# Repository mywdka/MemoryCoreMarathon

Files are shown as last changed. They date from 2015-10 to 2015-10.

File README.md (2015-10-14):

# MemoryCoreMarathon
UNRAVEL THE CODE IV, Memory Core Marathon

# Weaving, Driving, Dreaming

Based on the Memory Core Shield from B. North and O. Nash.
Slight routing modifications done to the driver layout, silkscreen and Arduino API.

WdKA API for Unravel the code can be found in the code/ folder.

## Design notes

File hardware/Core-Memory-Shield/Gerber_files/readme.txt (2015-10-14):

These are the RS-274X gerber files for both the core board and the driver board.

The filename extensions are as follows:

GBL Bottom layer (copper)
GTL Top layer (copper)

GBS Bottom soldermask
GTS Top soldermask

GBO Bottom overlay (silkscreen)
GTO Top overlay (silkscreen)

TXT Excellon drill file	(2.4 with leading zero suppression)

GTP Top paste (used to specify stencil - necessary only for driver board)

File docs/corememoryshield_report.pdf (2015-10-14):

## Magnetic core memory reborn

Ben North, Oliver Nash

May 9, 2011

Abstract

We outline the theory of magnetic core memory, and describe the design and fabrication of a core memory Arduino shield.

## 1 Introduction

### 1.1 What is magnetic core memory?

Magnetic core memory was the most widely used form of digital com- Core memory is an old puter memory from its birth in the early 1950s until the era of in- memory technology. tegrated-circuit memory began in the early 1970s. Aside from being
extremely reliable, magnetic core memory is an appealing technology
because it is based on a very simple idea.
A magnetic core is a ring of ferrite material. It can be permanently A core, a ring of magnetic
material, stores one bit by the direction of its
magnetisation.

magnetised either clockwise or anti-clockwise about its axis just as a vertical bar magnet can be magnetised up or down. We can then
turn a magnetic core into a bit of digital memory by letting these two
magnetisation states correspond to 0 and 1.
The core needs no power to retain its data. In other words, core It provides non-volatile memory is a form of non-volatile storage like modern hard disk drives, storage.
although in its day it fulfilled the ‘high-speed’ role of modern RAM.
With many such cores, large memory modules were made, such as
this example from a CDC machine of the mid-1960s. The right-hand
image shows a close-up of the cores themselves.

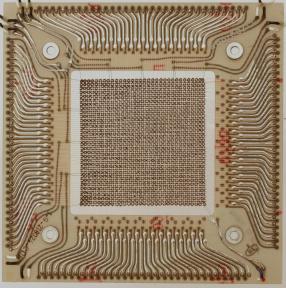
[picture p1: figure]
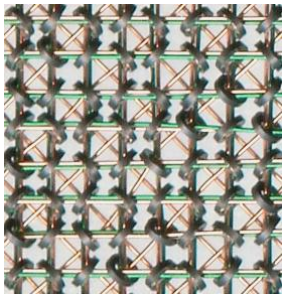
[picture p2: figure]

50 mm | 2 mm

1

Cores were c.1 mm across, | As the technology developed [1], the cores shrank from c.2 mm di-
and ran at c.1 MHz. Core stores had up to 500,000 cores. | ameter in the early 1950s to c.0·4 mm by the early 1970s. Access speeds
| rose at the same time, from about 200 kHz to over 1 MHz, and core
| memory modules were manufactured with as many as over half a mil-
| lion cores. Furthermore, as recently as 2004, a magnetic core memory
| system was found still in service in a telephony control system.
It is still an interesting | Magnetic core memory continues to capture the imaginations of
technology even today. | modern enthusiasts [2, 3], and it is also the origin of the term core
| dump, to mean an on-disk image of the main memory of a process.

### 1.2 What is an Arduino?

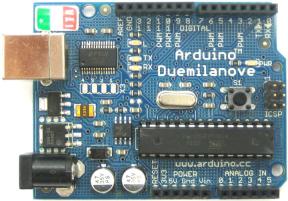
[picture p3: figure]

The Arduino is a popular, | The Arduino, whose Duemilanove version is shown above [5], is an
easy-to-use, open design microprocessor board with IO capabilities. | open-source physical computing device. It has removed many of the
| hurdles for people wishing to explore embedded microprocessing. An
| Arduino is a small single-board computer based on an Atmel AVR
| microprocessor, with supporting components to handle USB commu-
| nications and provide easy access to input/output pins. The developer
| programs the on-board microprocessor using an IDE running on a PC.
| It has proved very popular, with six-figure sales, and has been used
| in projects as diverse as autopilots for radio-controlled aeroplanes, and
| CNC sewing machines.
Add-on shields exist, | Several expansion modules exist, allowing the Arduino to perform
providing specialist interfacing or control functions. | a greater variety of tasks. These secondary modules, or shields, are
| circuit boards that plug into the Arduino’s pin headers, and supply
| additional hardware to, for example, drive motors or servos, interface
| with wireless communication modules, or communicate over Ethernet.

### 1.3 A core-store shield

We set ourselves the | We had developed an interest in the principles and practice of core
challenge of creating a core memory Arduino shield. | memory, and the creation of a modern core memory module struck us
| as an appealing challenge. Eventually a pleasing idea suggested itself:
| we decided to build a magnetic core memory Arduino shield.
New-old-stock cores; | Our project was made possible thanks to the existence of a sup-
modern components. | ply of surplus ferrite cores manufactured in the 1980s for the magnetic
| core memory systems of the time. We decided that we would use these
| old cores but permit ourselves to use modern components (transistors,
| integrated-circuit logic gates, etc.). This made our work enormously
| 2

easier than that of the original core memory inventors and manufacturers. Also, we knew that our end goal was possible.
We succeeded in building an extremely reliable 32-bit core memory It worked. shield for the Arduino. It can be used as storage for the Arduino, or alternatively, any modern computing device with a USB port can now
read and write to magnetic core memory.

## 2 Principles of core memory

### 2.1 Magnetic hysteresis

A ferrimagnetic substance has two distinct permanently magnetised states. In our case, these are clockwise and anti-clockwise round the cores. The key to their use as computer memory is their behaviour when an external magnetic field is applied — they exhibit hysteresis.

A weak external field has no effect
If we apply a weak external magnetic field around a core, and then remove it, there is no lasting effect on the core’s magnetisation:

Start off with a core magnetised in the anti-clockwise direction:

Apply a weak clockwise external field. This reduces the strength of the anti-clockwise magnetism in the core:

But when the external field is removed, the magnetism in the core ‘springs back’ to its original state:

A weak anti-clockwise field similarly produces no lasting change.

Strong external fields cause the magnetisation to switch However, if we apply a sufficiently strong magnetic field in the opposite direction, the core will switch from one magnetic state to the other:

Start off with a core magnetised in the anti-clockwise direction:

Apply a strong clockwise external field. This switches the core’s magnetism, and the core now has clockwise magnetism:

When this external field is removed, the magnetism in
the core reduces slightly in strength, but remains clockwise:

A strong field in the same direction as the core’s existing magnetisation has no lasting effect — the core is saturated and can be magnetised no further in that direction.

3

### 2.2 The magnetic field of a current-carrying wire

Current in a wire creates a | The next essential physical fact is that a DC current in a wire creates
magnetic field. | a magnetic field circulating about the wire, whose strength is propor-
tional to the size of the current. If we reverse the direction of the current, the magnetic field circulates in the opposite direction:

Small current down;
weak clockwise field

Large current down;
strong clockwise field

Small current up; weak
anti-c/w field
Large | current | up;
strong anti-c/w field

### 2.3 Writing to a one-bit core memory system

We can write a bit by We now know enough to write one bit of core memory. Having threaded
driving appropriate
currents.

a wire through a core, we can cause the core to become magnetised in the clockwise direction by passing a strong enough current in one direction through the wire, and we can cause the core to become magnetised in the anti-clockwise direction by passing a strong enough current in the opposite direction. These two operations correspond to writing 0 and 1 to the core. The magnetisation of the core, and so the bit stored, remains even after the current stops flowing.

The core is magnetised anti-clockwise, and therefore holds the bit 1. No current flows through the wire.

A large current is supplied, generating a strong magnetic field. This switches the core’s magnetisation to clockwise.

When the current is turned off, the core remains magnetised clockwise, therefore now holding 0.

### 2.4 Reading from a one-bit core memory system

But: how do we read the | Core memory would probably have been a lot less popular had it been
state of the core? | a write-only technology. To see how to read from the core, we need a
| further piece of physics: a changing magnetic field induces a voltage.
When a core switches, it | Consider a core which is magnetised anti-clockwise. If we apply
induces a voltage. | current which tries to increase this anti-clockwise magnetisation, it
| does not in fact change the magnetic field in the core much — it is
| already saturated. If, however, we apply enough current in the opposite
| direction, the core switches to be magnetised clockwise, as shown above.
| This process takes a small amount of time, around 1 µs for typical cores.
| 4

During that time, the magnetic field is undergoing a large change, and
so induces a noticeable voltage.
The setup for reading the state of a core then is to have two wires A second wire senses the
passing through the core. We use one wire, the drive line | induced voltage. , for driving
current back and forth and so to set the state of the core, and we have
circuitry connected to the second wire, the sense line, to measure the
induced voltages.
We start the process of reading the core by writing a 0 to it using To read: write a 0; check if
the core switched. If it
did, it was a 1.

the drive line. If we observe no significant induced voltage on the sense
line then we learn the core was already in state 0. If, however, we observe a large induced voltage on the sense line then we learn that
the core contained a 1 (and we then write 1 back to the core). The
memory is said to operate with a destructive read.
At this point it may help to make this more concrete by exhibiting We measured the sense signals from our cores. some real data. Below we present the results of one of our experiments in which we measured the induced voltage on the sense line when writing 0 to a core which contained 1, and when writing 0 to a core which
already contained 0.

If a core switches from one magnetisation
direction to the other, the changing magnetic field induces a voltage that peaks at c.35 mV, staying above 20 mV for c.600 ns:

However, if the applied field is in the same direction as the core’s existing magnetisation, no switching takes places, and we observe a negligible voltage:

20 mV

40 mV

2 µs pulse | 2 µs pulse

We also see voltage ‘spikes’ caused by the drive line currents switching on and off. These transformer-action spikes are significant in magnitude but are short and temporally separated from the switching signal. The pulse shown is in fact the base drive of transistors, and the turn-on and turn-off delays are visible.
We could now build a one-bit read-write core memory system.

### 2.5 Arrays of cores and half-select currents

However, we want to have more than one bit of memory without need- Imposing only half the field leaves the core alone. ing one drive line per core. We make use of a feature of the hysteresis behaviour of the core. We previously talked in terms of ‘weak’ or
‘strong’ external magnetic fields. Slightly more quantitatively: the core
is not switched by a field which is half as strong as one which is just
strong enough to switch the core. The field is proportional to the current in the drive line, so if we pass half the current required to just
switch a core through the drive line, the core will not switch state.
Now suppose we have nm cores and we arrange them in an n × m A 2-D array gives efficient control of every core. rectangular array such that each core has one of n horizontal and one
of m vertical drive lines passing through it. With this setup we can

5

selectively set the (i, j)th core and no other by simultaneously driving the ith vertical drive line and jth horizontal drive line in the appropriate directions, each with half the current required for switching. For example, in a 4×4 array, with the cores viewed edge-on, we switch the core shown:

One core receives a full field and switches.

Nine cores like this are completely unaffected.

Six cores like this receive a half-field and are unaffected.

We only need O(

√
N) drive lines for an array of N cores. In total, each core will have three wires threaded through it: two perpendicular drive lines, and a sense line. A single sense line can be threaded through all cores in an array, a point we return to below.

### 2.6 Exploiting anti-coincidence

One more trick doubles The picture we should now have in mind of a core memory module is
the number of cores we
can address.

a rectangular array of cores, with one vertical and one horizontal drive line passing through each core. There is a further drive-line economy, which cuts in half the number of drive lines in one dimension.
Two states out of four do | Consider a core with its two drive lines. There are then four combi-
nothing. | nations of current direction. Two combinations produce a reinforcing
field round the core, but in the other two, the fields cancel round the core:
Reinforce to write 0: | Reinforce to write 1: | Cancel; no effect: | Cancel; no effect:

We say the currents or fields are coincident if they reinforce, and anti-coincident if they cancel.
We can use those two | Now consider two cores arranged as below. We still have two drive
states. | lines, but we have turned one of the drive lines through two right angles
so that it passes through both cores but in opposite directions. If we now consider the four possible simultaneous states of the drive lines, we find that all possible combinations are put to use:
Write 0 to left core: | Write 1 to left core: | Write 0 to right core: | Write 1 to right core:

6

To take the concrete example of the small core array we built, we One sense loop snakes through all cores. show a 8 × 4 array. We also now illustrate the single sense line which runs through all cores. The alternating alignment of the cores makes
the threading of the sense loop easier, and also reduces the transformer-action spikes.

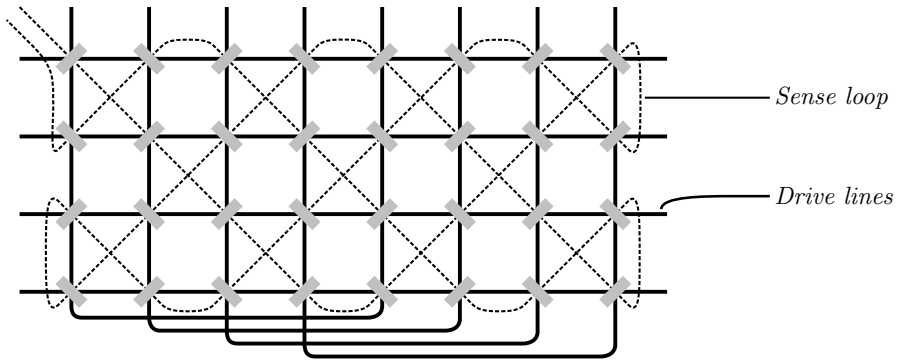
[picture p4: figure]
Sense loop; Drive lines

The array of cores can be thought of as two halves, with each core in the left half having an anti-coincident partner in the right half sharing the same pair of drive lines.

## 3 Our implementation

To implement these principles, we have to solve a few fairly distinct problems. We must be able to drive current through the drive lines; decide which drive lines need to have current driven through them; and sense when an induced ‘switching signal’ occurs.

### 3.1 A current-driving circuit

As noted above, we organise the 32-bit module as a rectangular array The drive circuit is two
copies (X and Y ) of one
problem: driving one of
four lines in either
direction.

with 4 rows and 8 columns in which the columns are paired as above using anti-coincidence. As a result, we have 4 vertical and 4 horizontal drive lines to control. Our current-driving problem is thus two instances
of the same problem: we need to be able to select one of four lines, and
to specify a direction in which to drive current along that line.
Our current sources and sinks are transistors, and we could ac- Drive the four lines as ‘two by two’. complish our goal by connecting each end of each drive line to the
collectors of both a PNP and an NPN transistor (i.e., by using four
H-bridge circuits). This would work, but would be inefficient in terms
of the number of transistors used. By introducing a few diodes, we can
use a design with half as many transistors.
By turning on the correct transistors in the following circuit, we can send current in either direction through any of the drive lines. The resistors R1 and R2 control how much current flows. We discuss their value below.

7

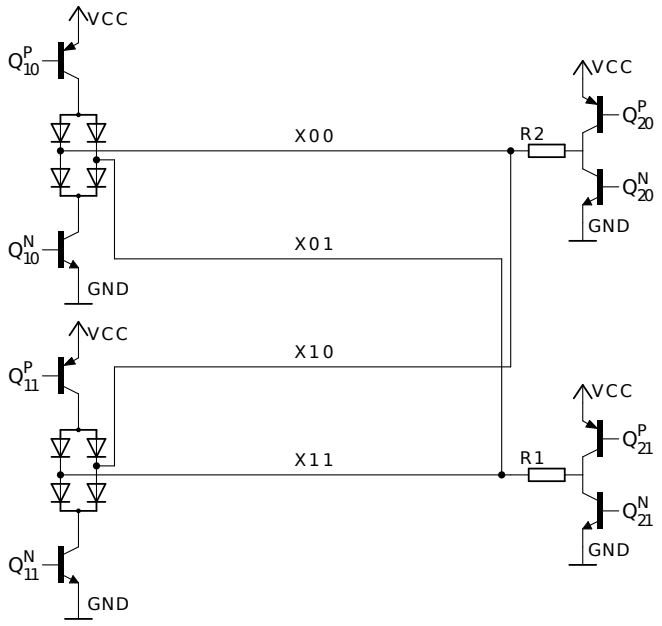
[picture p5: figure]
GND; VCC

Calibrating the half-select current

Experiments determine As we have already discussed, it is important that we drive the right
how much current we
should use.

amount of current. It must be low enough that the magnetic field produced by the current in one drive line is not enough to switch a core, but high enough that the combined field from two coincident currents does produce switching. We determined the range of possible values of current for our cores empirically and established that any value in the range 250–340 mA works. We set the current by choosing appropriate values for the resistors in the drive circuit above.

### 3.2 Addressing

Which transistors should | In the circuit above, we want to know which transistors to turn on
we turn on? | to drive current left or right in one of the four lines. We must be
able to pulse this current, and so we need to be able to stop all drive currents. Let the enable Boolean variable be E. Let the variable DX give the direction, with DX = 0 being leftwards. In order to drive the line XA1A2

in the direction DX (as long as E is asserted), the base of transistor QP
11, for example, must be taken high or low according to QP
11 = E ∧ DX ∧ A1· In words, QP
11 must be on (i.e., its base must be pulled low) exactly when we are enabled (E = 1) and we wish to drive current rightwards (DX = 1) through either X10 or X11 (those two lines have A1 = 1). The formulae for all eight transistors are:

QP
10 = E ∧ DX ∧ A1 QP
20 = E ∧ DX ∧ A2
QN

10 = E ∧ DX ∧ A1 QN
20 = E ∧ DX ∧ A2
QP

11 = E ∧ DX ∧ A1 QP
21 = E ∧ DX ∧ A2
QN

11 = E ∧ DX ∧ A1 QN
21 = E ∧ DX ∧ A2

8

Combining the X and Y drive addressing

Recall that the current-driving circuitry consists of two instances of this Translating from ‘currents
in lines’ to ‘address and
data’.

driving circuit, horizontal and vertical. We thus have bits A1, A2, and
DX for the first instance and A3, A4, and DY , say, for the second. We can generate a switching field in either direction for any of our 32 cores by choosing values for these six bits, and then controlling transistor bases accordingly. Furthermore, looking back at section 2.6, we see that the tuple (A1, A2, A3, A4) determines a pair of anti-coincident partner cores and that it is the value of A0 := DX ⊕ DY that distinguishes between these two partner cores. Therefore we reparameterise our six control bits in terms of the five-bit address A4A3A2A1A0 and the single data bit D := DX. We then have DY = DX ⊕A0. The 32 cores are now numbered, since each core has a unique five-bit address A4A3A2A1A0. The layout of these addresses in the 8 × 4 array may appear a little haphazard, but this does not matter.

### 3.3 Sensing

With the current-driving and addressing circuitry in place, it remains How to detect the bulging only to describe how to detect the presence or absence of a core- switching signal? switching signal on the sense line. We chose the comparator-based
circuit described in [1] (and apparently of unknown German origin):

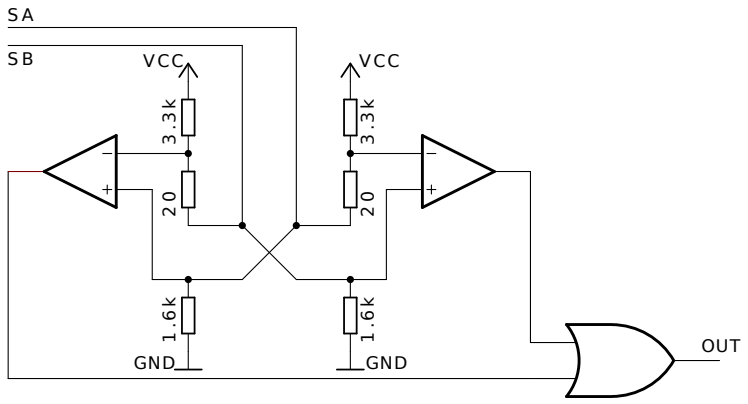
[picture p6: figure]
OUT; GND

VCC | VCC 3 .3 k 2 0 1 .6 k | 3 .3 k 2 0 1 .6 k

The sense line, described above, is threaded once through each of the
32 cores, and its ends are connected to the lines marked SA and SB.
The obvious two-fold symmetry of this circuit reflects the possibility Need to detect positive and negative sense bulges. that a sense pulse from a switching core can bias SA positively or negatively relative to SB depending on whether a core is switching
from a clockwise to an anti-clockwise magnetisation state relative to
the sense line or vice-versa.
The resistors ensure that, when no voltage is present across SA/SB, With an input of at least
±20 mV, one comparator’s
output goes high.

each comparator’s inverting input is 20 mV above its non-inverting, and
so both outputs are low. If a positive sense pulse occurs, causing SA to rise more than 20 mV above SB, the left comparator will detect this and output ‘high’. Conversely for a negative sense pulse, the right

9

comparator will fire. We or the two to detect pulses of either polarity. The threshold of 20 mV was chosen by experiment.
Capture sense output at The final detail of the sense circuitry is that we used a timed latch to
the right moment.

t=0 t=650ns:
latch sense output

t=2us

sense
threshold

catch and store the output of the or gate at the appropriate moment. This ensures that we are not affected by any high comparator outputs caused by the transformer-action spikes. The timer delay was chosen by experiment as 650 ns, although any value 500–900 ns worked.

## 4 Finished product

### 4.1 Complete circuit

Combining these pieces, we arrive at the final circuit, which we give in appendix A. The design splits the shield into a driver board and a plug-in core board, as shown in this photograph of the two boards plugged into the Arduino:

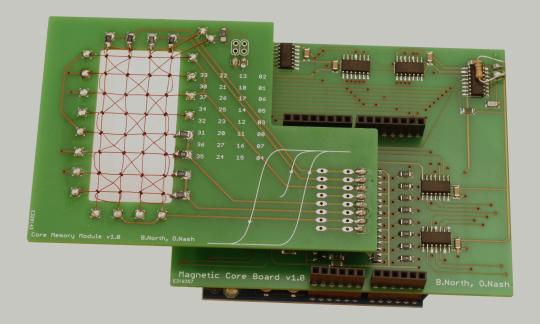
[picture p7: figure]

### 4.2 Fabrication

Our design files are | We finally achieved our goal of building a core memory shield by having
available. | our schematics fabricated as PCBs. Owing to some late design changes,
| we then had to patch the boards slightly; the circuits described here in-
| clude the changes. Eagle files for these schematics and PCBs as well as
| the Gerber files are available in the online version of this document [6].
| Also contained in the Eagle files are the part numbers for the various
| components (transistors, logic gates, comparators, etc.) that we used.

### 4.3 API and testing

How to write to and read | Once the core board, driver board and Arduino have been appropriately
from the cores from Arduino code. | mated, it is easy to use the Arduino to read from and write to the core
| memory array. To send a write pulse to a core, the Arduino writes the
| data bit to digital pin 8, writes the address of the core in question to
| 10

digital pins 3–7 and then asserts enable (digital pin 2) for 2 µs. Once this is done, reading digital pin 9 reveals whether the core changed state. Cycle time is such that a 32-bit operation takes 0·5 ms, although
preliminary experiments suggest that by being more aggressive on the
timings we could bring this down to 0·3 ms.
These operations are presented as the functions write_bit and A simple API and
serial-based CLI is
available.

read_bit. Loops turn these into write_word and read_word, to act
on the whole core board as a single 32-bit unsigned integer. A further natural operation is a bit exchange. This, in one operation, writes a new data bit to a core, and returns the old value, which can be deduced as (latched-sense-output) xor (new-data). The source-code for this API,
with a command-line interface presented on the serial port, is available
for download [6].
We used this interface to extensively test the core memory shield. The core memory shield
performed error-free for

### 10 bln operations, running

for 100 hrs.

After running continuously for over one hundred hours, the shield had performed over ten billion successful bit-exchange operations without a single error.

## 5 Final words

We hope that our work here might encourage others to take an interest in both the theory and the practice of core memory. For further reading, excellent descriptions are given by Hilpert [1] and by Jones [4]. Building a reliable 32-bit core memory shield for the Arduino proved to be a natural stopping point for our work, but there is certainly more that could be done. Some ideas for future work that appealed to us:

- Many core memory arrays from the heyday of core memory still exist and indeed are easy to find for sale (e.g., on eBay). It might be a fun challenge to build a driver module to write to and read from these old arrays. Perhaps with care and luck one could even recover some 50-year-old data?
- A completely different approach to core memory, with a nondestructive read cycle, was invented by Eiichi Goto in the mid-1950s, and was incorporated in the Japanese Parametron Computer 1 (see [7] for a description). It would be very interesting to re-implement this significantly different core memory technology.
- In practice, a group of core memory modules of the type described here, known as planes, were combined into a core store. All planes could be accessed simultaneously by introducing an inhibit line [4]. Constructing an 8-bit wide store would be a worthwhile challenge.

11

## A Circuits

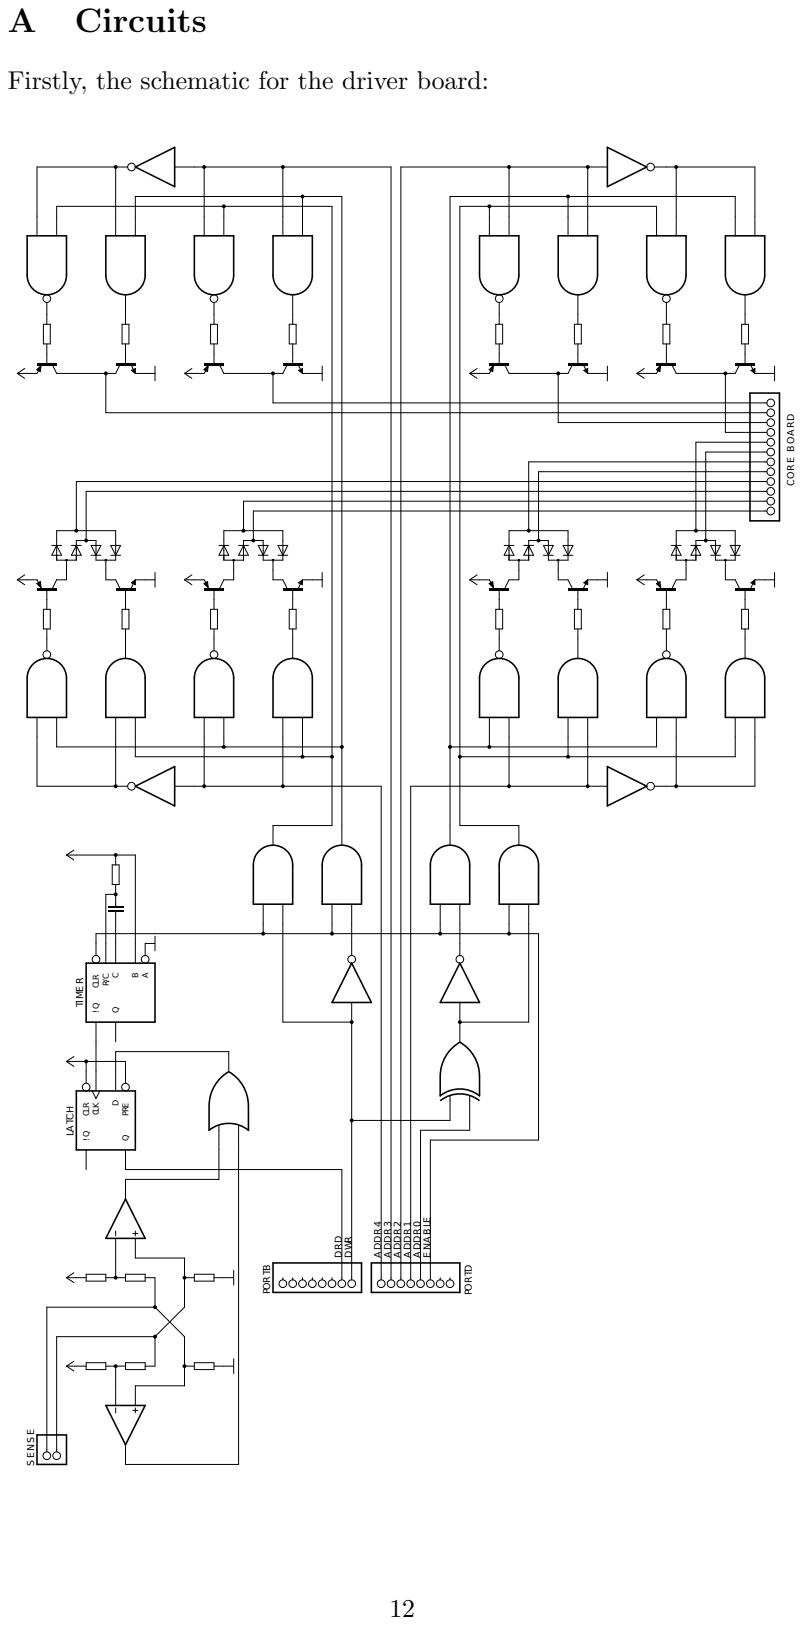
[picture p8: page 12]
DRD DWR; ADDR4; ADDR3; ADDR2; ADDR1; ADDR0; E NABLE; !Q CLR; CLK; PRE Q; LATCH; CLR; TIME R; PORTB; PORTD; CORE BOARD

Firstly, the schematic for the driver board:

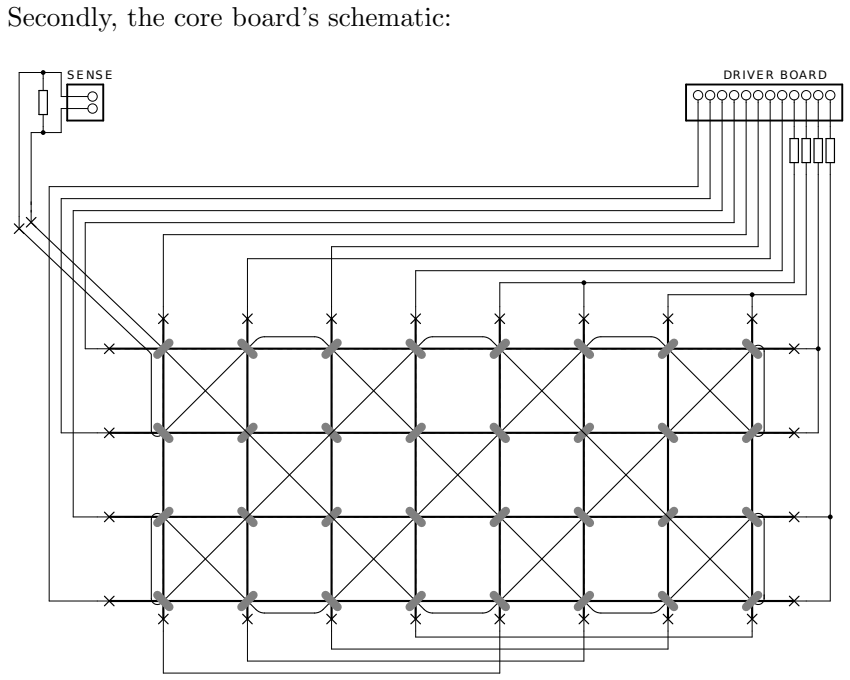
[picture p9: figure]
Secondly, the core board’s schematic:; DRIVE R BOARD

The terminating resistor across the sense loop provides a path for the current caused by the induced voltage round the loop.

## References

[1] B. Hilpert. Magnetic core memory systems. http://www.cs.ubc.ca/~hilpert/e/coremem/index.html.
[2] W. Holder. One bit ferrite core memory. http://sites.google.com/site/wayneholder/one-bit-ferrite-core-memory.
[3] A. Holme. Magnetic core memory. http://www.holmea.demon.co.uk/Core/Flipper.htm.
[4] J.R. Jones. Coincident current ferrite core memories. Byte, 11:6–16, July 1976.
[5] D. Mellis. Photograph of Arduino Duemilanove, cc-by-2·0. http: //www.flickr.com/photos/mellis/4784965878/.
[6] B. North and O. Nash. Magnetic core memory reborn. http: //www.corememoryshield.com/.
[7] E. Wada. The Parametron Computer PC-1 and its initial input routine. In P. Rojas and U. Hashagen, editors, The first computers: History and architecture, pages 435–452. MIT Press, 2000.

13

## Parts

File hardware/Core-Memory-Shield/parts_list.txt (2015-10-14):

Below is the list of necessary parts for building a magnetic core memory
Arduino shield v1.1.  We found all of these parts (including the cores
themselves) easily available on at least one of http://www.ebay.com and
http://www.farnell.com and had our PCBs manufactured by
http://www.eurocircuits.com.

One important note is that the value of the four drive resistors, listed
as 18ohm, may need to be adjusted if the cores used are sufficiently
different to ours.

DRIVING:
8x 2N4401/MMBT4401 transistor (SOT-23 package)
8x 2N4403/MMBT4403 transistor (SOT-23 package)
17x 220ohm 1% resistor (1206 package)
4x 18ohm 1% resistor (1206 package) [May need calibration as described above.]
4x BAW56 diode pair (SOT-23 package)
4x BAV70 diode pair (SOT-23 package)

SENSING:
2x 1.3k 1% resistor (1206 package)
2x 3.3k 1% resistor (1206 package)
2x 20ohm 1% resistor (1206 package)
1x dual MAX907CPAS comparator (SO08 package)
2x 4.7k resistor (1206 package)

LATCHING, TIMING:
1x dual 74HC74D latch (SO14 package)
1x dual 74HC123D timer (SO16 package)
1x 47pF capacitor (1206 package)
1x 12.5k resistor (1206 package)

ADDRESSING:
1x hex 74HC04D (SO14 package)
1x quad 74HC86D (SO14 package)
3x quad 74HC08D (SO14 package)
2x quad 74HC00D (SO14 package)

BYPASS/FILTER CAPS:
10x 0.1uF tantalum capacitor (1206 package)
1x 47uF tantalum capacitor (1206 package)

CONNECTIONS:
2x 0.1" (1x8)-pin header (Arduino stackable)
2x 0.1" (1x6)-pin header (Arduino stackable)
1x 0.1" (1x12)-pin header (male)
1x 0.1" (1x2)-pin header (male)
1x 0.1" (1x12)-pin header (female)
1x 0.1" (1x2)-pin header (female)

PCBs:
1x North-Nash driver board v1.1
1x Laser-cut stencil for driver board v1.1
1x North-Nash core board v1.1
~10g solder paste

CORES:
32x ~1mm hard ferrite cores (with wide hysteresis loop)
Several metres of 0.20mm diameter glazed copper wire.

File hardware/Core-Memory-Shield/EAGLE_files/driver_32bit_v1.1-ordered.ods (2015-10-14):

Qty | Value | Parts | Description
Resistors
2 | 3.3k | R1, R4 | RESISTOR, European symbol
2 | 20 | R2, R5 | RESISTOR, European symbol
2 | 1.6k | R3, R6 | RESISTOR, European symbol
16 | 220 | R8, R9, R11, R12, R14, R15, R17, R18, R20, R21, R23, R24, R26, R27, R29, R30 | RESISTOR, European symbol
1 | 12.5k | R31 | RESISTOR, European symbol
2 | 4.7k | R32, R33 | RESISTOR, European symbol
1 | 1.5k | R34 | RESISTOR, European symbol
Capacitors
1 | 50pF | C0 | CAPACITOR, European symbol
10 | 0.1uF | C1, C2, C3, C4, C5, C6, C7, C8, C9, C10 | CAPACITOR, European symbol
1 | 47uF | C11 | CAPACITOR, European symbol
Transistors
8 | 2N4401 | T1, T3, T5, T7, T9, T11, T13, T15 | NPN Transistror
8 | 2N4403 | T2, T4, T6, T8, T10, T12, T14, T16 | PNP Transistror
Diodes
4 | BAW56 | D1, D2, D5, D6 | Dual DIODE Cathode-Anode|Anode-Cathode
4 | BAV70 | D3, D4, D7, D8 | Dual DIODE Anode-Cathode|Cathode-Anode
IC
1 | 74HC74D | IC1 | Dual D type positive edge triggered FLIP FLOP, preset and clear
1 | 74HC123D | IC2 | Retriggerable monostable MULTIVIBRATOR
1 | MAX907CPASO08 | IC3 | COMPARATOR
3 | 74HC08D | IC4, IC7, IC10 | Quad 2-input AND gate
1 | 74HC04D | IC5 | Hex INVERTER
1 | 74HC86D | IC6 | Quad 2-input EXCLUSIV-OR (XOR) gate
2 | 74HC00D | IC8, IC9 | Quad 2-input NAND gate
Headers
1 | PORTB | JP2 | PIN HEADER
1 | PORTD | JP1 | PIN HEADER
1 | ANALOG | JP5 | PIN HEADER
1 | PWR | JP4 | PIN HEADER
1 | SENSE | JP3 | PIN HEADER
1 | CORE BOARD | JP6 | PIN HEADER

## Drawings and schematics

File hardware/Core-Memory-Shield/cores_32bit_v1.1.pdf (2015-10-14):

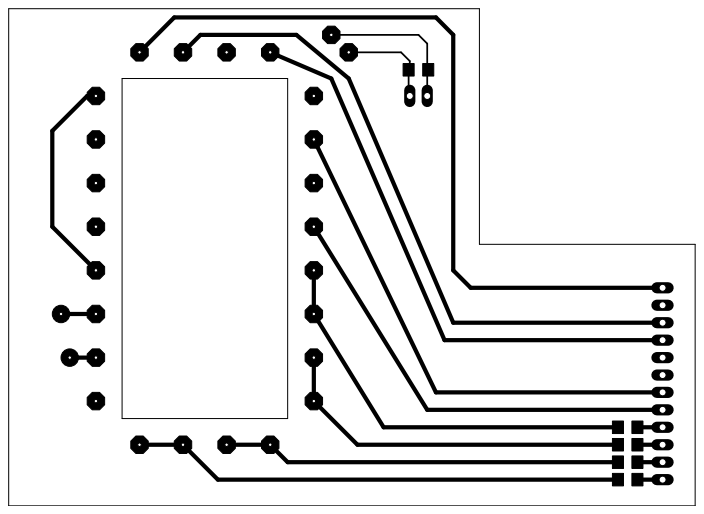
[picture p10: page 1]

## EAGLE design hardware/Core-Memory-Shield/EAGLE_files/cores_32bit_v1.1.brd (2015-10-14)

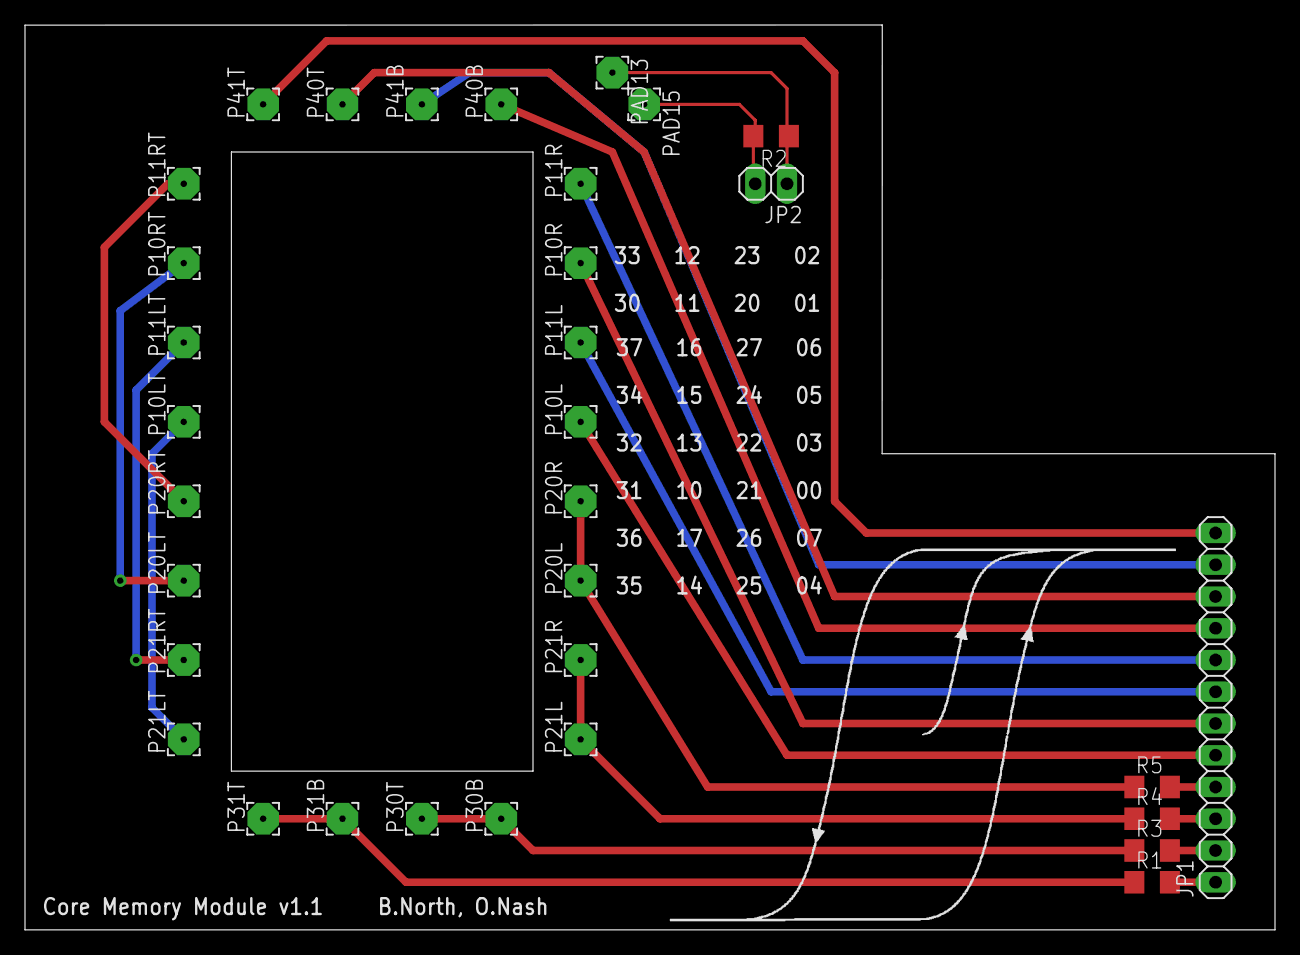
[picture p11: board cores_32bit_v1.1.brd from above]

Board: 2 copper layers, 100.0 x 72.4 mm, 33 parts (0 on the bottom side), 22 nets.

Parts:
JP1: DRIVER BOARD; 1X12
JP2: SENSE; 1X02
P10L, P10LT, P10R, P10RT, P11L, P11LT, P11R, P11RT, P20L, P20LT, P20R, P20RT, P21L, P21LT, P21R, P21RT, P30B, P30T, P31B, P31T, P40B, P40T, P41B, P41T: WIREPAD2,54/1,1; 2,54/1,1
PAD13, PAD15: WIREPAD2,54/1,1; 2,54/1,1
R1, R3, R4, R5: 18; R1206
R2: 220; R1206

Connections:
D10A: JP1.5, P10L.1
D10B: JP1.6, P10R.1
D11A: JP1.7, P11L.1
D11B: JP1.8, P11R.1
D20: P20L.1, P20R.1, R5.1
D21: P21L.1, P21R.1, R4.1
D30: P30B.1, P30T.1, R3.1
D31: P31B.1, P31T.1, R1.1
D40A: JP1.9, P40B.1
D40B: JP1.10, P40T.1
D41A: JP1.11, P41B.1
D41B: JP1.12, P41T.1
unnamed: JP2.1, PAD13.1, R2.1
unnamed: JP2.2, PAD15.1, R2.2
unnamed: JP1.1, R1.2
unnamed: JP1.2, R3.2
unnamed: JP1.3, R4.2
unnamed: JP1.4, R5.2
unnamed: P10LT.1, P21LT.1
unnamed: P11LT.1, P21RT.1
unnamed: P10RT.1, P20LT.1
unnamed: P11RT.1, P20RT.1

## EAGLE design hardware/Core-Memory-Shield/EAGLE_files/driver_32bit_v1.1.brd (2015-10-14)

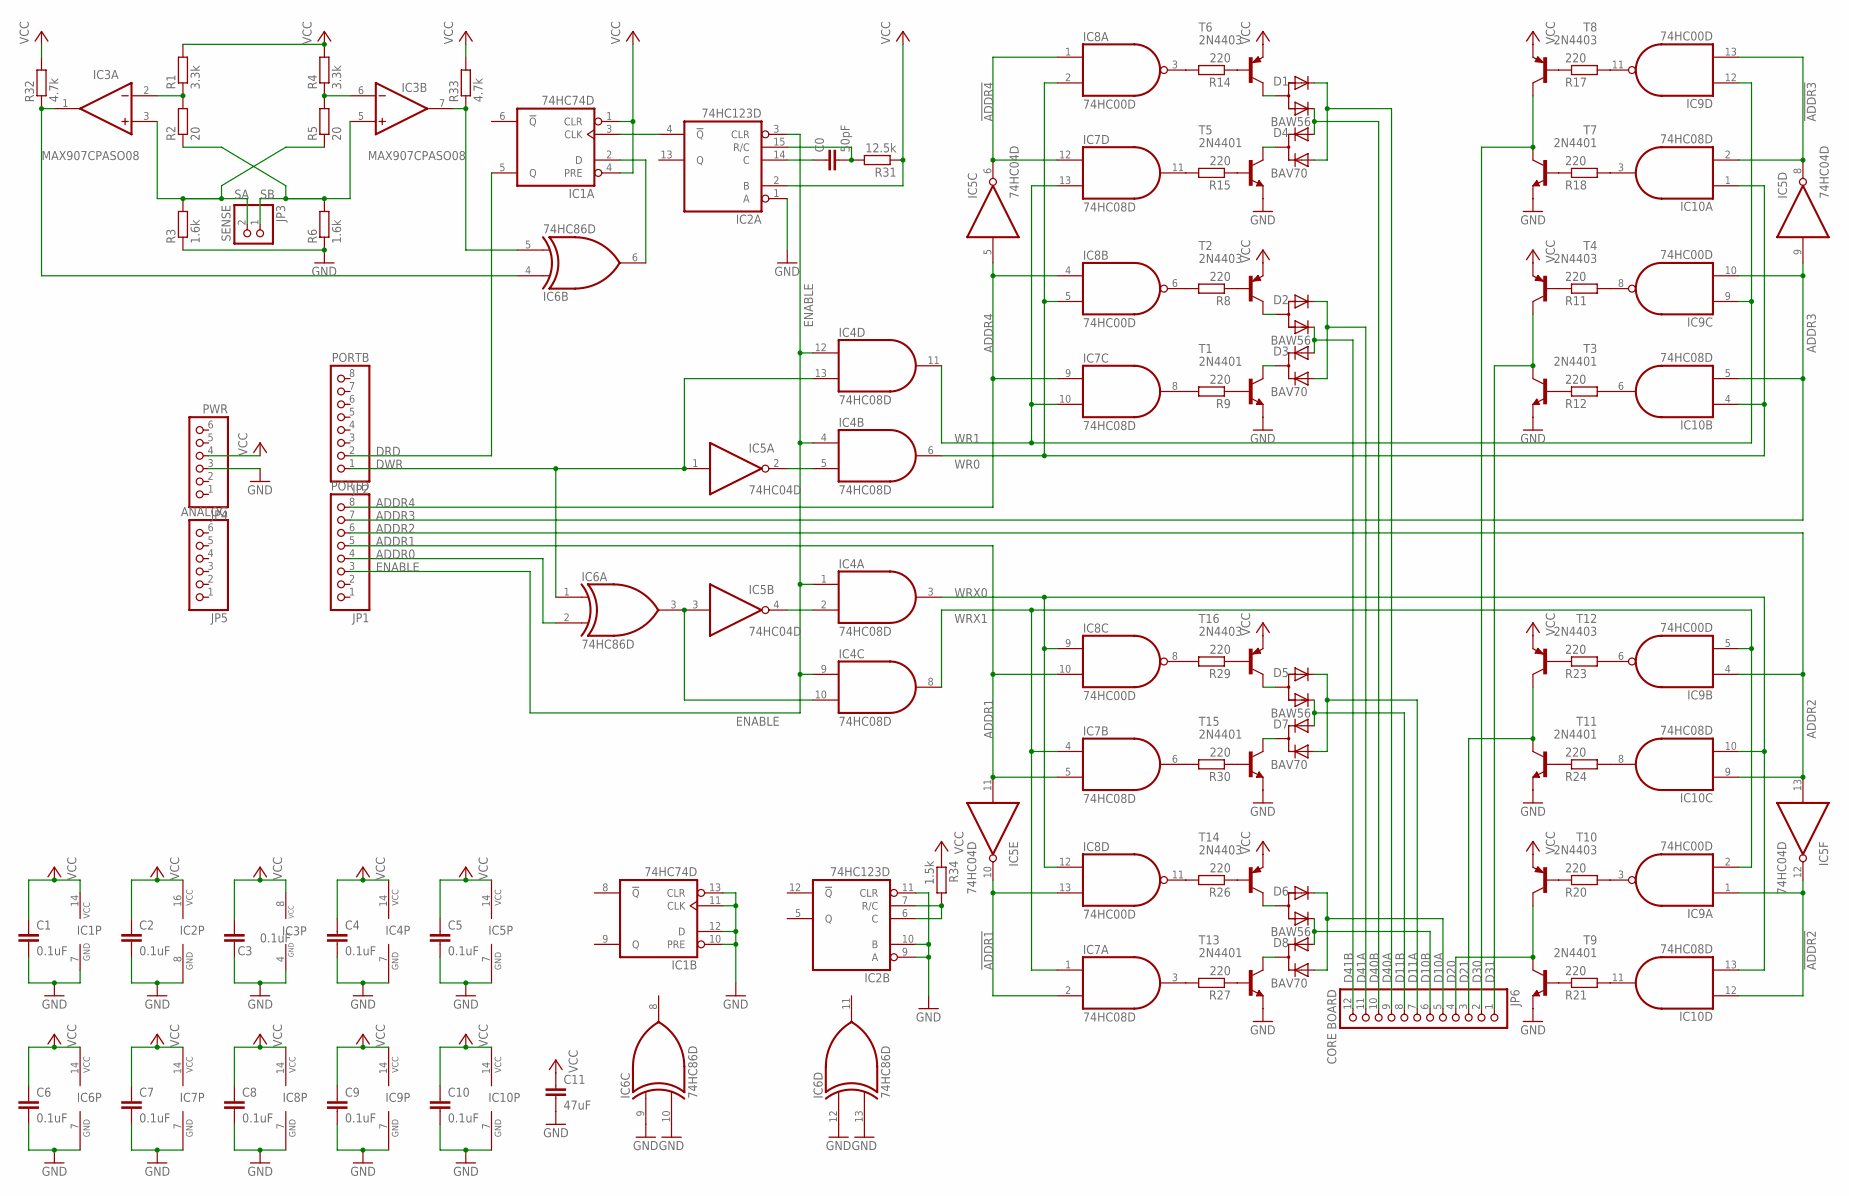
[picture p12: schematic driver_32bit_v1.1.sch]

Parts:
C0: 50pF; C1206
C1, C2, C3, C4, C5, C6, C7, C8, C9, C10: 0.1uF; C1206
C11: 47uF; C1206
D1, D2, D5, D6: BAW56; SOT23; MPN BAW56
D3, D4, D7, D8: BAV70; SOT23; MPN BAV70
IC1: 74HC74D; SO14; MPN SN74HC74D
IC2: 74HC123D; SO16; MPN 74HC123D
IC3: MAX907CPASO08; SO08
IC4, IC7, IC10: 74HC08D; SO14; MPN SN74HC08D
IC5: 74HC04D; SO14; MPN SN74HC04D
IC6: 74HC86D; SO14; MPN 74HC86D
IC8, IC9: 74HC00D; SO14; MPN 74HC00D-Q100,118
JP1: PORTD; 1X08
JP2: PORTB; 1X08
JP3: SENSE; 1X02
JP4: PWR; 1X06
JP5: ANALOG; 1X06
JP6: CORE BOARD; 1X12
R1, R4: 3.3k; R1206
R2, R5: 20; R1206
R3, R6: 1.6k; R1206
R8, R9, R11, R12, R14, R15, R17, R18, R20, R21, R23, R24, R26, R27, R29, R30: 220; R1206
R31: 12.5k; R1206
R32, R33: 4.7k; R1206
R34: 1.5k; R1206
T1, T3, T5, T7, T9, T11, T13, T15: 2N4401; SOT23-BEC; MPN 2N4401RLRPG
T2, T4, T6, T8, T10, T12, T14, T16: 2N4403; SOT23-BEC

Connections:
!ADDR1: IC5.10 (O), IC7.2 (I1), IC8.13 (I1)
!ADDR2: IC5.12 (O), IC9.1 (I0), IC10.12 (I0)
!ADDR3: IC5.8 (O), IC9.13 (I1), IC10.2 (I1)
!ADDR4: IC5.6 (O), IC7.12 (I0), IC8.1 (I0)
ADDR0: IC6.2 (I1), JP1.4
ADDR1: IC5.11 (I), IC7.5 (I1), IC8.10 (I1), JP1.5
ADDR2: IC5.13 (I), IC9.4 (I0), IC10.9 (I0), JP1.6
ADDR3: IC5.9 (I), IC9.10 (I1), IC10.5 (I1), JP1.7
ADDR4: IC5.5 (I), IC7.9 (I0), IC8.4 (I0), JP1.8
D10A: D6.1 (K2), D8.2 (A2), JP6.5
D10B: D6.2 (K1), D8.1 (A1), JP6.6
D11A: D5.1 (K2), D7.2 (A2), JP6.7
D11B: D5.2 (K1), D7.1 (A1), JP6.8
D20: JP6.4, T9.C, T10.C
D21: JP6.3, T11.C, T12.C
D30: JP6.2, T7.C, T8.C
D31: JP6.1, T3.C, T4.C
D40A: D1.1 (K2), D4.2 (A2), JP6.9
D40B: D1.2 (K1), D4.1 (A1), JP6.10
D41A: D2.1 (K2), D3.2 (A2), JP6.11
D41B: D2.2 (K1), D3.1 (A1), JP6.12
DRD: IC1.5 (Q), JP2.2
DWR: IC4.13 (I1), IC5.1 (I), IC6.1 (I0), JP2.1
ENABLE: IC2.3 (CLR), IC4.1 (I0), IC4.4 (I0), IC4.9 (I0), IC4.12 (I0), JP1.3
GND: C1.2, C2.2, C3.1, C4.2, C5.2, C6.2, C7.2, C8.2, C9.2, C10.2, C11.2, IC1.7 (GND), IC1.10 (PRE), IC1.11 (CLK), IC1.12 (D), IC1.13 (CLR), IC2.1 (A), IC2.8 (GND), IC2.9 (A), IC2.10 (B), IC2.11 (CLR), IC3.4 (GND), IC4.7 (GND), IC5.7 (GND), IC6.7 (GND), IC6.9 (I0), IC6.10 (I1), IC6.12 (I0), IC6.13 (I1), IC7.7 (GND), IC8.7 (GND), IC9.7 (GND), IC10.7 (GND), JP4.3, R3.1, R6.1, T1.E, T3.E, T5.E, T7.E, T9.E, T11.E, T13.E, T15.E
unnamed: IC3.2 (-IN), R1.1, R2.2
unnamed: IC3.6 (-IN), R4.1, R5.2
unnamed: IC2.6 (C), IC2.7 (R/C), R34.2
unnamed: D1.3 (A), T6.C
unnamed: D2.3 (A), T2.C
unnamed: D5.3 (A), T16.C
unnamed: R8.1, T2.B
unnamed: R9.1, T1.B
unnamed: D3.3 (C), T1.C
unnamed: R11.1, T4.B
unnamed: R12.1, T3.B
unnamed: IC9.11 (O), R17.2
unnamed: IC10.3 (O), R18.2
unnamed: D4.3 (C), T5.C
unnamed: D6.3 (A), T14.C
unnamed: R17.1, T8.B
unnamed: R18.1, T7.B
unnamed: R14.1, T6.B
unnamed: R15.1, T5.B
unnamed: IC7.11 (O), R15.2
unnamed: IC8.3 (O), R14.2
unnamed: IC7.8 (O), R9.2
unnamed: IC8.6 (O), R8.2
unnamed: R20.1, T10.B
unnamed: R21.1, T9.B
unnamed: R23.1, T12.B
unnamed: R24.1, T11.B
unnamed: IC9.3 (O), R20.2
unnamed: IC1.3 (CLK), IC2.4 (!Q)
unnamed: IC1.2 (D), IC6.6 (O)
unnamed: IC3.7 (OUT), IC6.5 (I1), R33.1
unnamed: IC3.1 (OUT), IC6.4 (I0), R32.1
unnamed: C0.1, IC2.14 (C)
unnamed: C0.2, IC2.15 (R/C), R31.2
unnamed: IC4.5 (I1), IC5.2 (O)
unnamed: D7.3 (C), T15.C
unnamed: D8.3 (C), T13.C
unnamed: IC10.11 (O), R21.2
unnamed: IC4.2 (I1), IC5.4 (O)
unnamed: IC4.10 (I1), IC5.3 (I), IC6.3 (O)
unnamed: IC9.8 (O), R11.2
unnamed: R26.1, T14.B
unnamed: IC10.6 (O), R12.2
unnamed: R27.1, T13.B
unnamed: IC9.6 (O), R23.2
unnamed: IC10.8 (O), R24.2
unnamed: R29.1, T16.B
unnamed: R30.1, T15.B
unnamed: IC7.6 (O), R30.2
unnamed: IC8.8 (O), R29.2
unnamed: IC7.3 (O), R27.2
unnamed: IC8.11 (O), R26.2
SA: IC3.3 (+IN), JP3.2, R3.2, R5.1
SB: IC3.5 (+IN), JP3.1, R2.1, R6.2
VCC: C1.1, C2.1, C3.2, C4.1, C5.1, C6.1, C7.1, C8.1, C9.1, C10.1, C11.1, IC1.1 (CLR), IC1.4 (PRE), IC1.14 (VCC), IC2.2 (B), IC2.16 (VCC), IC3.8 (VCC), IC4.14 (VCC), IC5.14 (VCC), IC6.14 (VCC), IC7.14 (VCC), IC8.14 (VCC), IC9.14 (VCC), IC10.14 (VCC), JP4.4, R1.2, R4.2, R31.1, R32.2, R33.2, R34.1, T2.E, T4.E, T6.E, T8.E, T10.E, T12.E, T14.E, T16.E
WR0: IC4.6 (O), IC8.2 (I1), IC8.5 (I1), IC10.1 (I0), IC10.4 (I0)
WR1: IC4.11 (O), IC7.10 (I1), IC7.13 (I1), IC9.9 (I0), IC9.12 (I0)
WRX0: IC4.3 (O), IC8.9 (I0), IC8.12 (I0), IC10.10 (I1), IC10.13 (I1)
WRX1: IC4.8 (O), IC7.1 (I0), IC7.4 (I0), IC9.2 (I1), IC9.5 (I1)

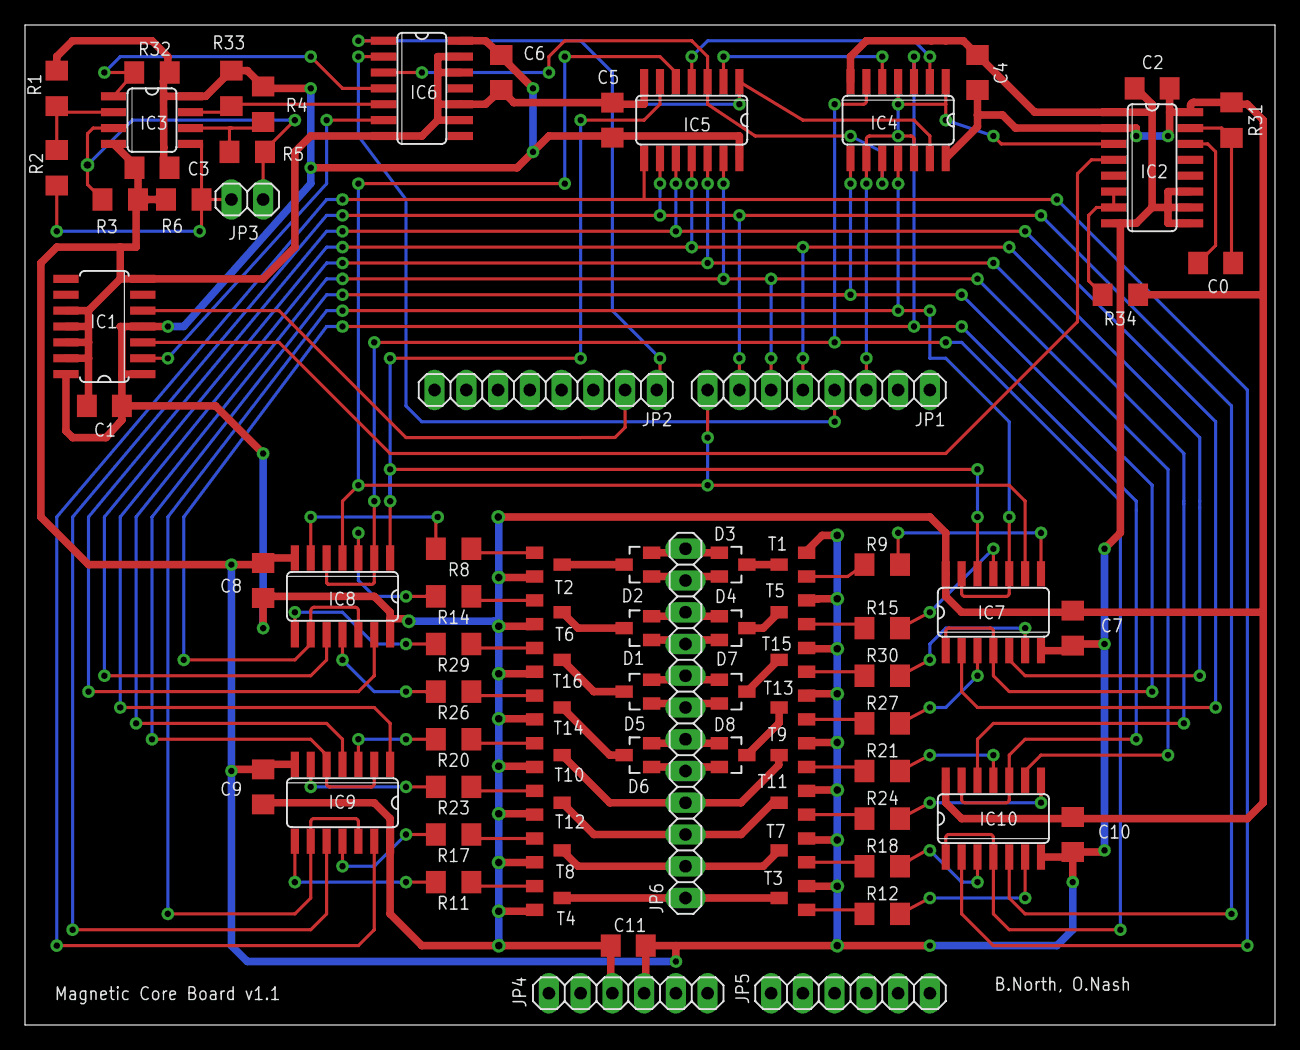
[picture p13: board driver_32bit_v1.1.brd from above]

Board: 2 copper layers, 100.0 x 80.0 mm, 78 parts (0 on the bottom side), 84 nets.

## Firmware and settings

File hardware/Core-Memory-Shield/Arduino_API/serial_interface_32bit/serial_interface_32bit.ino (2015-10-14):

// Rough-and-ready Arduino code for testing, calibrating and using core memory shield.
//
// Copyright 2011 Ben North and Oliver Nash.
//
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
#define ADDRSIZE      5
#define WORDSIZE      (1 << ADDRSIZE)
#define ENABLE        B00000100 // PORTD
#define DRD           B00000010 // PORTB
#define DWR           B00000001 // PORTB

static unsigned int WRITE_ON_US  = 2;
static unsigned int WRITE_OFF_US = 2; // May not be necessary.

static unsigned long errs = 0;
static unsigned int sense_test_addr = 0;
static int n_test_iters = 1000;
static char report_errors_p = 0;
static char trace_core_calls_p = 0;

void write_bit(byte n, const int v)
{
  if (trace_core_calls_p)
  {
    char buf[64];
    sprintf(buf, "x[0%02o] <- %d", n, v);
    Serial.println(buf);
  }

  // Assert 0 <= n <= 31, v == 0 or 1.
  noInterrupts();
  if(v == 0)
  {
    PORTB &= (~DWR);
  }
  else
  {
    PORTB |= DWR;
  }
  PORTD = ((n << 3) & (~ENABLE));
  PORTD |= ENABLE; // Enable separately to be safe.
  delayMicroseconds(WRITE_ON_US);
  PORTD &= (~ENABLE);
  delayMicroseconds(WRITE_OFF_US);
  interrupts();
}

int exchg_bit(byte n, const int v)
{
  write_bit(n, v);

  if(PINB & DRD)
  {
    // Switching occurred so core held opposite of
    // what we just set it to.

    if (trace_core_calls_p)
      Serial.println("___ -> CHANGE");

    return !v;
  }
  else
  {
    // No switching occurred so core held whatever
    // we just wrote to it.

    if (trace_core_calls_p)
      Serial.println("___ -> NO-CHANGE");

    return v;
  }
}

int read_bit(const int n)
{
  char buf[64];
  if (trace_core_calls_p)
  {
    sprintf(buf, "x[0%02o] -> ___", n);
    Serial.println(buf);
  }

  write_bit(n, 0);
  if(PINB & DRD)
  {
    // Switching occurred so core held 1.

    if (trace_core_calls_p)
      Serial.println("___ -> 1");

    write_bit(n, 1); // Put it back!
    return 1;
  }
  else
  {
    // No switching occurred so core held 0 (and still holds it).

    if (trace_core_calls_p)
      Serial.println("___ -> 0");

    return 0;
  }
}

void write_word(unsigned long v)
{
  int n;
  for(n = 0; n < WORDSIZE; n++)
  {
    write_bit(n, v & 1);
    v >>= 1;
  }
}

unsigned long read_word(void)
{
  unsigned long v = 0;
  int n;
  for(n = WORDSIZE-1; n >= 0; n--)
  {
    v <<= 1;
    v |= read_bit(n);
  }
  return v;
}

unsigned long exchg_word(unsigned long v)
{
  unsigned long v_prev;
  int n;
  for (n = 0; n < WORDSIZE; ++n)
  {
    unsigned long b = exchg_bit(n, v & 1);
    v >>= 1;
    v_prev >>= 1;
    v_prev |= (b << 31);
  }
  return v_prev;
}

static void maybe_report_error(int i, int j, const char * lbl)
{
  char buf[64];

  if (!report_errors_p)
    return;

  sprintf(buf, "(%o, %o): %s", i, j, lbl);
  Serial.println(buf);
}

static void toggle_error_reporting()
{
  char buf[64];
  report_errors_p = !report_errors_p;
  sprintf(buf, "report-errors-p now %d", report_errors_p);
  Serial.println(buf);
}

static void toggle_tracing()
{
  char buf[64];
  trace_core_calls_p = !trace_core_calls_p;
  sprintf(buf, "trace-core-calls-p now %d", trace_core_calls_p);
  Serial.println(buf);
}

static void current_calibration()
{
  Serial.print("pulsing for current calibration...");
  while (Serial.available() == 0)
  {
    int i;
    for (i = 0; i < WORDSIZE; ++i)
    {
      write_bit(i, 0);
      write_bit(i, 1);
    }
    delayMicroseconds(100);
  }
  Serial.println(" stopped");
  Serial.read(); /* discard typed character */
}

static void timing_exchange_word()
{
  unsigned long val_0 = read_word();
  unsigned long i;
  
  Serial.print("start...");
  for (i = 0; i < 12000; ++i)
  {
    exchg_word(val_0);
    exchg_word(val_0);
    exchg_word(val_0);
    exchg_word(val_0);
    exchg_word(val_0);
    exchg_word(val_0);
    exchg_word(val_0);
    exchg_word(val_0);
    exchg_word(val_0);
    exchg_word(val_0);
  }
  Serial.println("stop");
}

static void echo_comment()
{
  Serial.print("# ");
  char c;
  do {
    while (Serial.available() == 0);
    c = Serial.read();
    Serial.print(c, HEX);
  } while (c != '\r');
  Serial.println("");
}

static void corewise_set_test()
{
  char buf[64];
  for (int b = 0; b < 2; ++b)
  {
    errs = 0;
    for (int n = 0; n < n_test_iters; ++n)
      for (int i = 0; i < WORDSIZE; ++i)
      {
        write_bit(i, b);
        if (read_bit(i) != b) ++errs;
      }
    sprintf(buf, "set %d %lu %d", b, errs, n_test_iters);
    Serial.println(buf);
  }
}

static void corewise_interfere_test()
{
  char buf[64];
  for (int b0 = 0; b0 < 2; ++b0)
  {
    for (int b1 = 0; b1 < 2; ++b1)
    {
      errs = 0;
      for (int n = 0; n < n_test_iters; ++n)
      {
        for (int i = 0; i < WORDSIZE; ++i)
        {
          for (int j = 0; j < WORDSIZE; ++j)
          {
            if (j == i) continue;
            
            write_bit(i, b0);
            write_bit(j, b1);
            if (read_bit(i) != b0) {
              if (report_errors_p)
              {
                // Redundant test but sprintf() takes time.
                sprintf(buf, "%d %d", b0, b1);
                maybe_report_error(i, j, buf);
              }
              ++errs;
            }
          }
        }
      }
      sprintf(buf, "interfere %d %d %lu %d", b0, b1, errs, n_test_iters);
      Serial.println(buf);
    }
  }
}

static void corewise_tests()
{
  corewise_set_test();
  corewise_interfere_test();
}

static void R_test()
{
  unsigned long d = read_word();
  Serial.print("Core data read: 0x");
  Serial.print(d, HEX);
  Serial.print(" = B");
  Serial.println(d, BIN);
}

static void s_test()
{
  char buf[64];
  write_bit(sense_test_addr, 0);
  write_bit(sense_test_addr, 0);
  write_bit(sense_test_addr, 1);
  write_bit(sense_test_addr, 1);
  sprintf(buf, "Pulsed core 0%02o", sense_test_addr);
  Serial.println(buf);
}

static void report_sense_addr()
{
  char buf[64];
  sprintf(buf, "Ready to pulse core 0%02o", sense_test_addr);
  Serial.println(buf);
}

static void a_test()
{
  sense_test_addr += 1;
  sense_test_addr %= 32;
  report_sense_addr();
}

static void A_test()
{
  sense_test_addr -= 1;
  sense_test_addr %= 32;
  report_sense_addr();
}

static void W_test()
{
  int i, x;
  unsigned long d = 0;
  Serial.print("Please enter 8 hexadecimal digits: ");
  for(i = 0; i < 8; i++)
  {
    d <<= 4;
    while(Serial.available() == 0) ;
    x = Serial.read();
    if('0' <= x && x <= '9')
    {
      d += x - '0'; 
    }
    else if('A' <= x && x <= 'F')
    {
      d += x - 'A' + 10;
    }
    else if('a' <= x && x <= 'f')
    {
      d += x - 'a' + 10;
    }
    else
    {
      Serial.print("Assuming 0 for non-hexadecimal digit: ");
      Serial.println(x, HEX);
    }
  }
  write_word(d);
  Serial.print("\r\nCore data write: 0x");
  Serial.print(d, HEX);
  Serial.print(" = B");
  Serial.println(d, BIN);
}

static void X_test()
{
  char buf[64];
  int i, x;
  unsigned long d1, d = 0;
  Serial.print("Please enter 8 hexadecimal digits: ");
  for(i = 0; i < 8; i++)
  {
    d <<= 4;
    while(Serial.available() == 0) ;
    x = Serial.read();
    if('0' <= x && x <= '9')
    {
      d += x - '0'; 
    }
    else if('A' <= x && x <= 'F')
    {
      d += x - 'A' + 10;
    }
    else if ('a' <= x && x <= 'f')
    {
      d += x - 'a' + 10;
    }
    else
    {
      Serial.print("Assuming 0 for non-hexadecimal digit: ");
      Serial.println(x, HEX);
    }
  }
  d1 = exchg_word(d);
  Serial.print("\r\nCore data write: 0x");
  sprintf(buf, "%08lx; read 0x%08lx", d, d1);
  Serial.println(buf);
}

static void r_test()
{
  int i, x, a = 0;
  Serial.print("Please enter address of bit to read: ");
  for(i = 0; i < ADDRSIZE; i++)
  {
    a <<= 1;
    while(Serial.available() == 0) ;
    x = Serial.read();
    if(x != '0') // Assert x == '1'
    {
      a += 1;
    }
  }
  Serial.print("\r\nCore data read from address: ");
  Serial.print(a, BIN);
  Serial.print(" found: ");
  Serial.println(read_bit(a));
}

static void w_test()
{
  int i, x, a = 0;
  Serial.print("Please enter address of bit to write: ");
  for(i = 0; i < ADDRSIZE; i++)
  {
    a <<= 1;
    while(Serial.available() == 0) ;
    x = Serial.read();
    if(x != '0') // Assert x == '1'
    {
      a += 1;
    }
  }
  Serial.print("\r\nPlease enter bit to write: ");
  while(Serial.available() == 0) ;
  x = Serial.read();
  Serial.print("\r\nCore data write to address: ");
  Serial.print(a, BIN);
  Serial.print(" value: ");
  if(x == '0')
  {
    write_bit(a, 0);
    Serial.println("0");
  }
  else // Assert x == '1'
  {
    write_bit(a, 1);
    Serial.println("1");
  }
}

static void t_test()
{
  int i;
  unsigned long d;
  for(i = 0; i < WORDSIZE; i++)
  {
    write_bit(i, 0);
    d = read_bit(i);
    Serial.print("Address (");
    Serial.print(i >> 3);
    Serial.print(i & 7);
    Serial.print(") ");
    Serial.print(i, BIN);
    Serial.print("   wrote 0 read ");
    Serial.print(d);
    write_bit(i, 1);
    d = read_bit(i);
    Serial.print("   wrote 1 read ");
    Serial.println(d);
  }
}

static void T_test()
{
  unsigned long d;
  int i, j;
  Serial.print("log10(iters)? ");
  while(Serial.available() == 0) ;
  int n = Serial.read() - '0';
  if (n < 0 || n > 9)
      Serial.println("bad power-of-10 arg to T");
  else
  {
    unsigned long n_iters = 1, n_iters_done = 0;
    while (n--) n_iters *= 10;
    errs = 0;
    for (n_iters_done = 0; n_iters_done < n_iters; ++n_iters_done)
    {
      for(i = 0; i < WORDSIZE; i++)
      {
        for(j = 0; j < WORDSIZE; j++)
        {
          if(j == i) { continue; }

          write_bit(i, 0);
          d = read_bit(i);
          if(d != 0) { errs++; maybe_report_error(i, j, "0-0"); }
          d = read_bit(i);
          if(d != 0) { errs++; maybe_report_error(i, j, "0-1"); }

          write_bit(i, 0);
          write_bit(j, 0);
          d = read_bit(i);
          if(d != 0) { errs++; maybe_report_error(i, j, "000"); }
          d = read_bit(i);
          if(d != 0) { errs++; maybe_report_error(i, j, "001"); }

          write_bit(i, 0);
          write_bit(j, 1);
          d = read_bit(i);
          if(d != 0) { errs++; maybe_report_error(i, j, "010"); }
          d = read_bit(i);
          if(d != 0) { errs++; maybe_report_error(i, j, "011"); }

          write_bit(i, 1);
          d = read_bit(i);
          if(d != 1) { errs++; maybe_report_error(i, j, "1-0"); }
          d = read_bit(i);
          if(d != 1) { errs++; maybe_report_error(i, j, "1-1"); }

          write_bit(i, 1);
          write_bit(j, 0);
          d = read_bit(i);
          if(d != 1) { errs++; maybe_report_error(i, j, "100"); }
          d = read_bit(i);
          if(d != 1) { errs++; maybe_report_error(i, j, "101"); }

          write_bit(i, 1);
          write_bit(j, 1);
          d = read_bit(i);
          if(d != 1) { errs++; maybe_report_error(i, j, "110"); }
          d = read_bit(i);
          if(d != 1) { errs++; maybe_report_error(i, j, "111"); }
        }
      }
      if (n_iters_done % 100 == 0)
      {
        Serial.print(n_iters_done, DEC);
        Serial.print(" iters; ");
        Serial.print(errs, DEC);
        Serial.println(" errors");
      }
    }
    Serial.print(n_iters_done, DEC);
    Serial.print(" iters; ");
    Serial.print(errs, DEC);
    Serial.println(" errors");
  }
}

static void U_test()
{  
  unsigned long n_iters_done = 0;
  unsigned long prev_datum = 0UL;
  errs = 0;
  write_word(prev_datum);
  while (1)
  {
    if (Serial.available() > 0)
    {
      (void)Serial.read();
      Serial.println("stopping");
      break;
    }
    unsigned rnd_0 = random(0x10000);
    unsigned rnd_1 = random(0x10000);
    unsigned long rnd = (unsigned long)(rnd_1) << 16 | rnd_0;
    unsigned long read_datum = exchg_word(rnd);
//          sprintf(buf, "rnd %08lx; read %08lx", rnd, read_datum);
//          Serial.println(buf);
    if (read_datum != prev_datum)
      ++errs;
    prev_datum = rnd;
    if (n_iters_done % 20000 == 0)
    {
      char buf[64];
      sprintf(buf, "%lu iters-done; %lu errors", n_iters_done, errs);
      Serial.println(buf);
    }
    ++n_iters_done;
  }
}

void setup(void) 
{
  DDRD |= B11111100;
  PORTD = (~ENABLE);
  DDRB |= DWR;
  DDRB &= (~DRD);
  Serial.begin(115200);
  randomSeed(0xdeadbeef);
  Serial.println("Welcome! If you're new, try using the commands 'r', 'w', 't' and 'R', 'W', 'T' to get started.");
}

void loop(void)
{
  byte c;
  if(Serial.available() > 0)
  {
    c = Serial.read();
    switch(c)
    {
    case 'c':
      current_calibration();
      break;
    case '#':
      echo_comment();
      break;
    case 'e':
      corewise_tests();
      break;
    case 'v':
      toggle_tracing();
      break;
    case 'f':
      toggle_error_reporting();
      break;
    case 'm':
      timing_exchange_word();
      break;
    case 'R':
      R_test();
      break;
    case 's':
      s_test();
      break;
    case 'a':
      a_test();
      break;  
    case 'A':
      A_test();
      break;
    case 'W':
      W_test();
      break;
    case 'X':
      X_test();
      break;
    case 'r':
      r_test();
      break;
    case 'w':
      w_test();
      break;
    case 't':
      t_test();
      break;
    case 'T':
      T_test();
      break;
    case 'U':
      U_test();
      break;
    case 'z':
      errs = 0;
      Serial.println("error-count = 0");
      break;
    default:
      Serial.print("Ignoring unknown command: ");
      Serial.print(c, HEX);
      Serial.print(" ");
      Serial.println(c, HEX);
    }
  }
}

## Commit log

2015-10-14 Updated comment field of magnet_core_shield.ino
2015-10-14 Added pdf of cores board

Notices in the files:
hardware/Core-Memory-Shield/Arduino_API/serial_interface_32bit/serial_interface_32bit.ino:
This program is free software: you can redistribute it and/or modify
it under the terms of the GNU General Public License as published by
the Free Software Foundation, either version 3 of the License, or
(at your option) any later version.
